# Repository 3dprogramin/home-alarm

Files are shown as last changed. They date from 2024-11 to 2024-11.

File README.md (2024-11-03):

# Home Alarm

**Home Alarm** is an Arduino-based project designed for home security. This project utilizes an ESP32 microcontroller, a PIR sensor for motion detection, an RGB LED, and a keypad for user interactions. The system communicates with an Express.js server to ensure robust notifications and intruder alerts.

<p align="center">
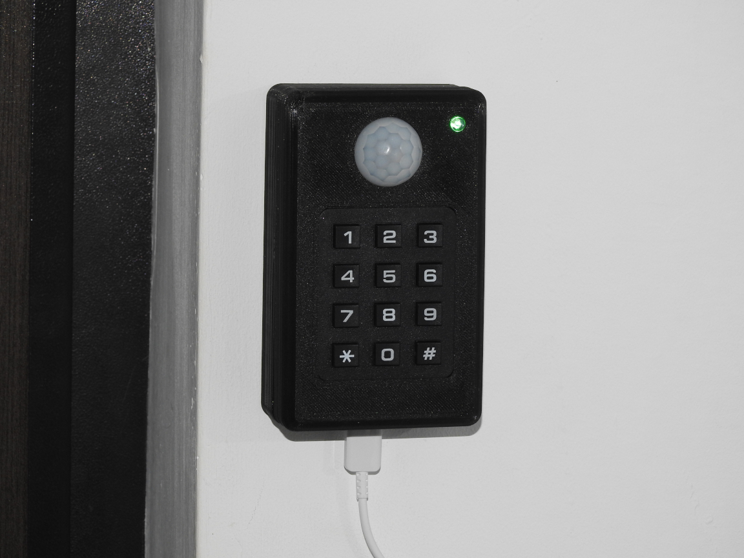
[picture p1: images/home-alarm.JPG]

</p>

## Project Structure
```perl
home-alarm/
├── src/               # Arduino code (PlatformIO)
├── server/            # Express.js server code
├── schematics/        # Wiring schematics (KiCad and PDF)
└── design/            # 3D design files (FreeCAD and .obj)
```

## Overview

The **Home Alarm** system operates as follows:
1. **Startup & Connection**: The ESP32 connects to a predefined WiFi network upon startup.
2. **Arming**: Press the * key on the keypad to activate the alarm. The system provides a 15-second grace period to exit the room without triggering the alarm.
3. **Detection & Notification**: 
   - If the PIR sensor detects motion while armed, the system initiates a 30-second window for PIN entry.
   - If the correct PIN is entered, the system disarms itself and sends a notification to the server to stop any further alerts.
   - Failure to enter the correct PIN within 30 seconds triggers the Express.js server to send an alert via Discord.
4. **Self-Arming**: If the system remains inactive for 12 hours and no motion is detected, it arms itself automatically.
5. **LED Indicators**:
   - **Green**: Powered on but not armed.
   - **Red**: Armed and ready.
   - **Blue**: Motion detected and awaiting PIN entry.
  
## Requirements

### Hardware
- **ESP32 Microcontroller**
- **PIR sensor**
- **RGB LED** (and 3 x 220 ohm resistors)
- **3x4 Matrix Keypad**
- **3D printer** for printing the case
  
### Software
- **PlatformIO** for Arduino code development
- **Node.js** for running the Express.js server
- **KiCad** for viewing/modifying schematics (*optional*)
- **FreeCAD** for viewing/modifying 3D design files (*optional*)

## Configuration

Before uploading the Arduino code, modify the following variables in `src/main.cpp`:

```cpp
const char *ssid = "YOUR_WIFI_SSID";
const char *password = "YOUR_WIFI_PASSWORD";
const char *serverURL = "YOUR_API_SERVER_URL";
const char *serverToken = "YOUR_API_SERVER_TOKEN";  // something unique, make sure the same token is used in server
const char *alarmPin = "YOUR_ALARM_PIN";            // e.g 1234#
```

There are other configurations that can be modified to your own needs, most of them being defined with `#define`

## Server Configuration

1. Navigate to the `server/` directory
2. Copy the `.env.sample` file and rename it to `.env`
3. Modify the variables in the `.env` file as needed:

```bash
PORT=3000
TOKEN=your_server_token
TRIGGER_DELAY=30000
DISCORD_WEBHOOK_ACTIVATED=https://discord.com/api/webhooks/your_activated_webhook
DISCORD_WEBHOOK_TRIGGER=https://discord.com/api/webhooks/your_trigger_webhook
```

The `TOKEN` inside your arduino code and the token inside the server need to match. It is used to authenticate the API calls made from the device to the server.

## Installation

### Arduino Code

1. Ensure **PlatformIO** is installed in your IDE (e.g., VSCode).
2. Navigate to `src/` folder
3. Upload the code to your ESP32

### Server Code

1. Navigate to the `server/` folder
2. Run the following commands:

```bash
npm install
npm start
```

## Operation

1. Power on the device.
2. Once connected to WiFi, arm the system by pressing the `*` key.
3. Leave the room within 15 seconds.
4. If an intruder is detected, enter the correct PIN on the keypad within 30 seconds to disarm.
5. If not disarmed, the Express.js server sends a Discord notification.

## Schematics and Design

- **Schematics**: The wiring schematics are created in **KiCad** and rendered to PDF for easy viewing. The original KiCad project files are included for any custom modifications.
- **3D Design**: The design is created in **FreeCAD** and exported to .obj files for use in 3D printing or rendering. The original FreeCAD project files are also included for custom modifications.

## License

This project is open-source and available under the MIT License.

## Contributing

Feel free to fork the repository, submit pull requests, or open issues for improvements or bug fixes.

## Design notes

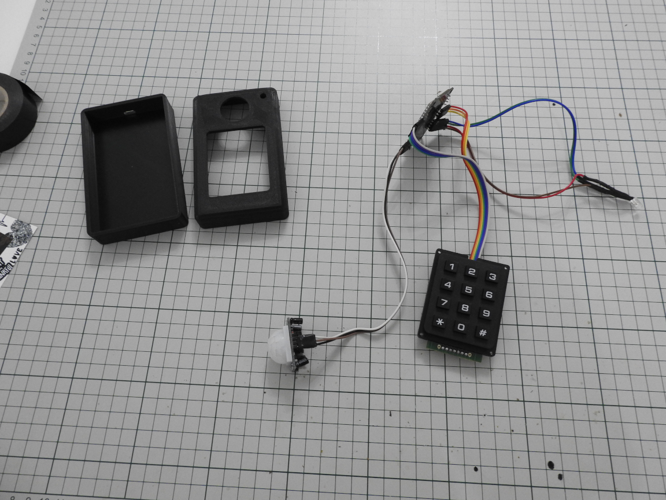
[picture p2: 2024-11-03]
images/before-mount.JPG

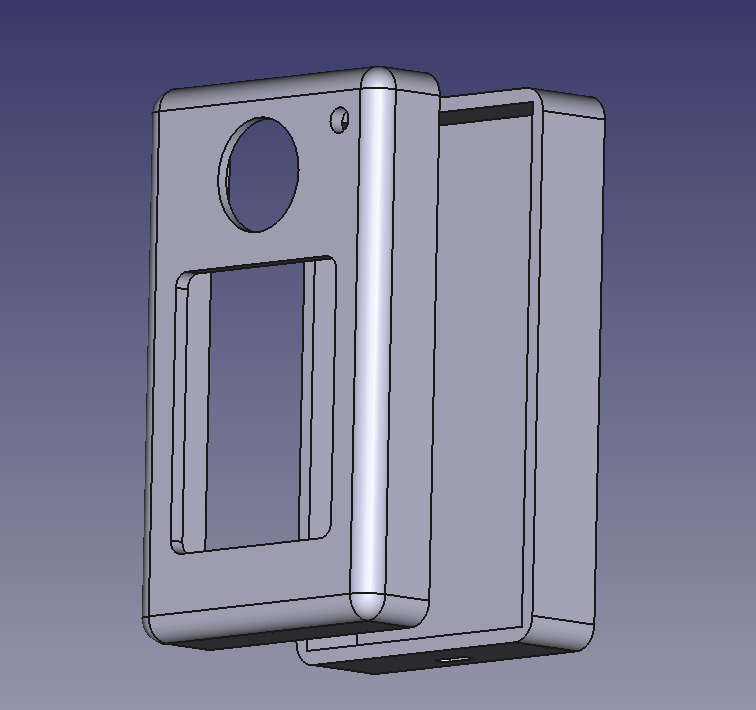
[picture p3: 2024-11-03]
images/case.png

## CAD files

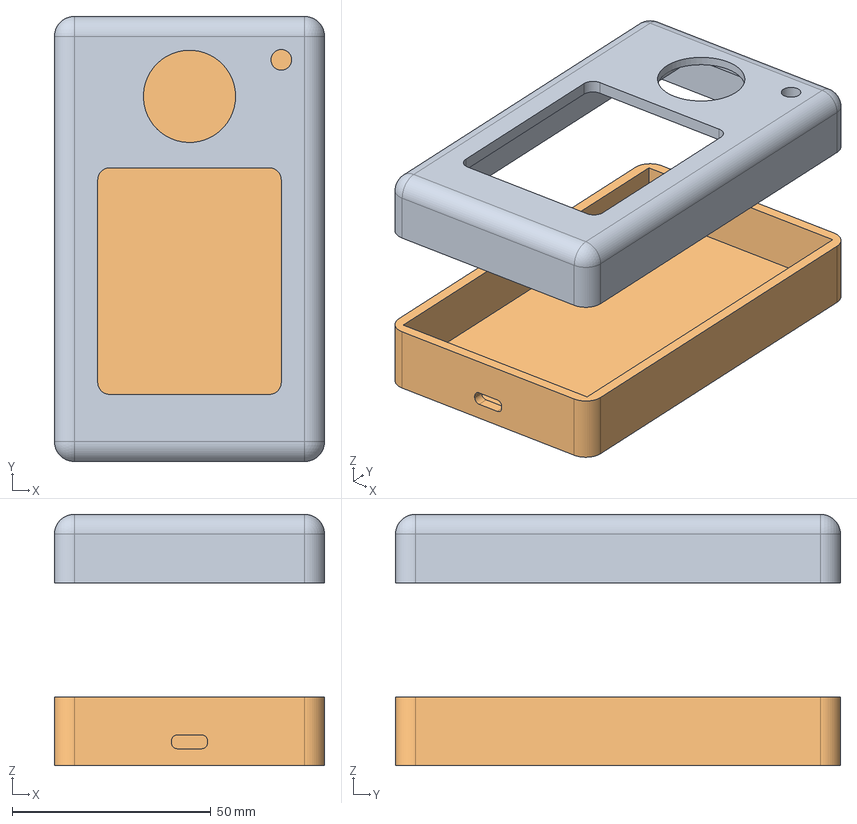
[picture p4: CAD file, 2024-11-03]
design/home-alarm.FCStd
68.0 x 112.0 x 63.2 mm
front
back

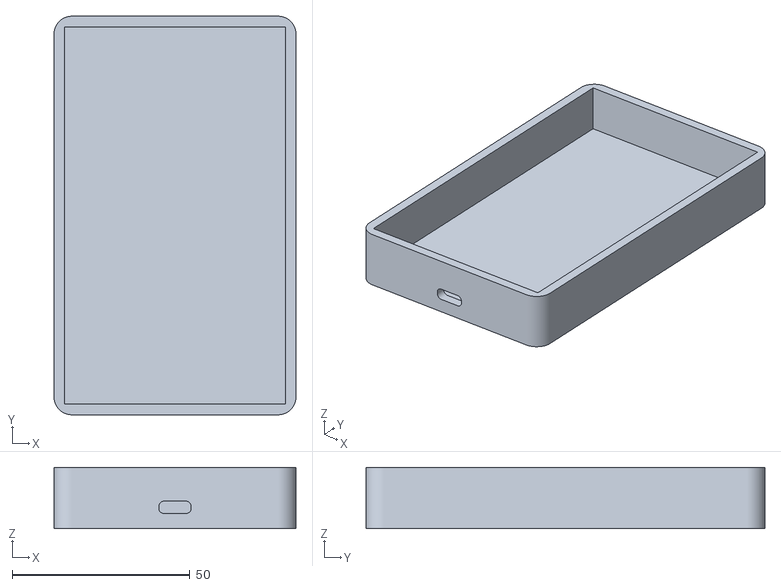
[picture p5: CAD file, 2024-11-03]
design/back.obj
68.0 x 112.0 x 17.2

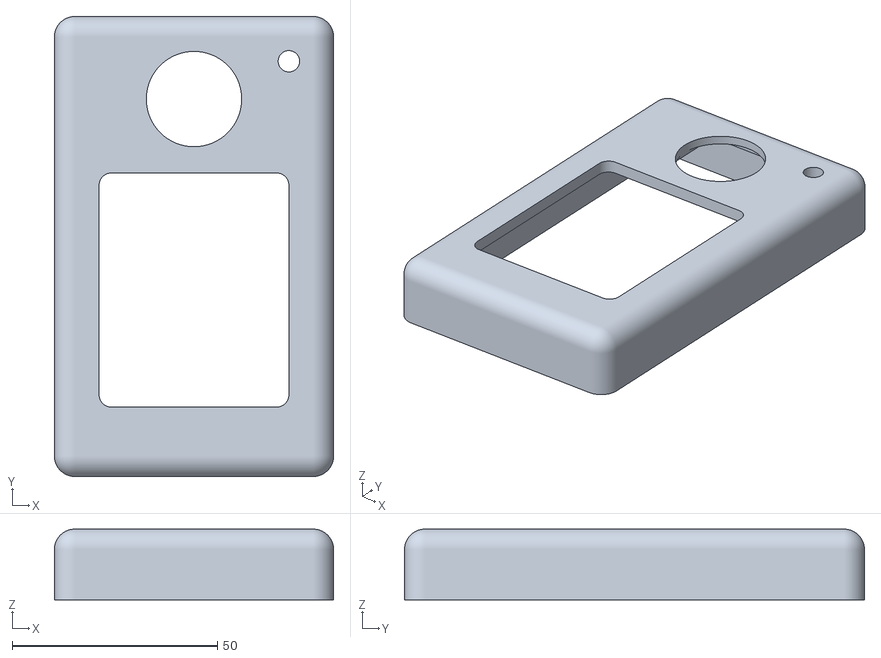
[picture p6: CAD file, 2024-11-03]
design/front.obj
68.0 x 112.0 x 17.2

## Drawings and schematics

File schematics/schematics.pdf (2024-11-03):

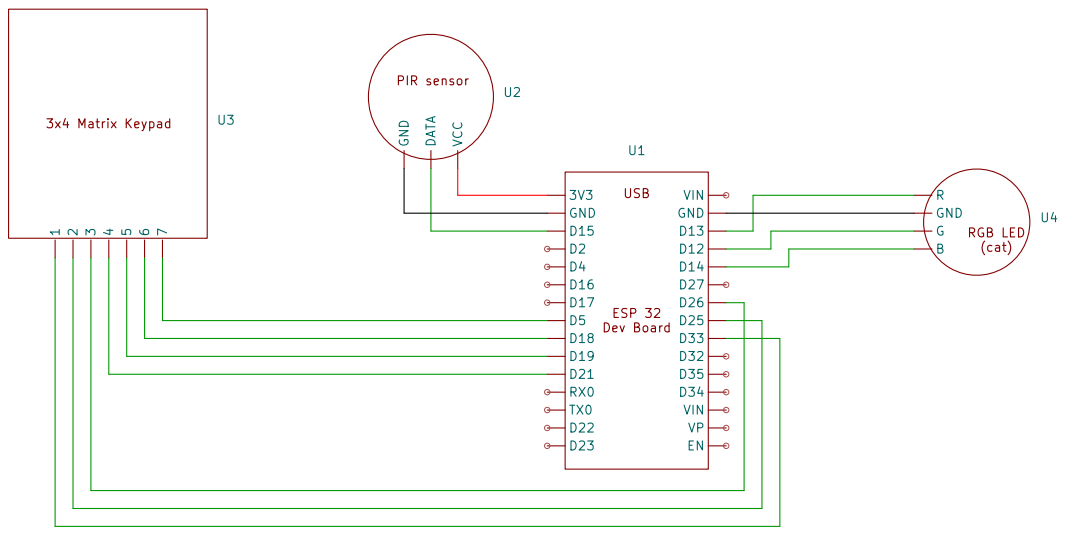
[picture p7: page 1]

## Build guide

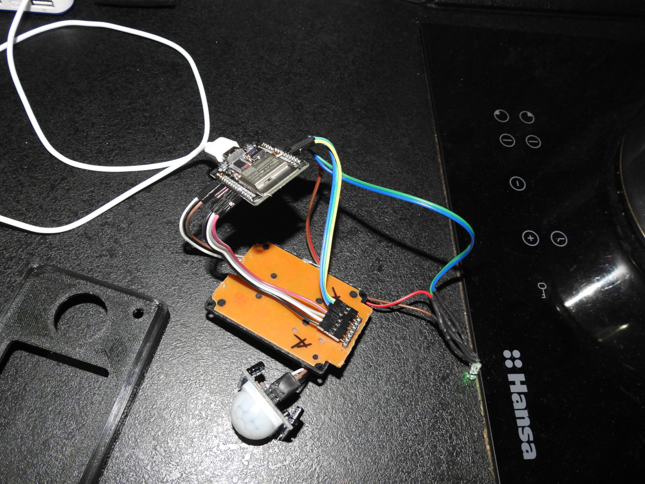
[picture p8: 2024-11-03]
images/wiring.JPG

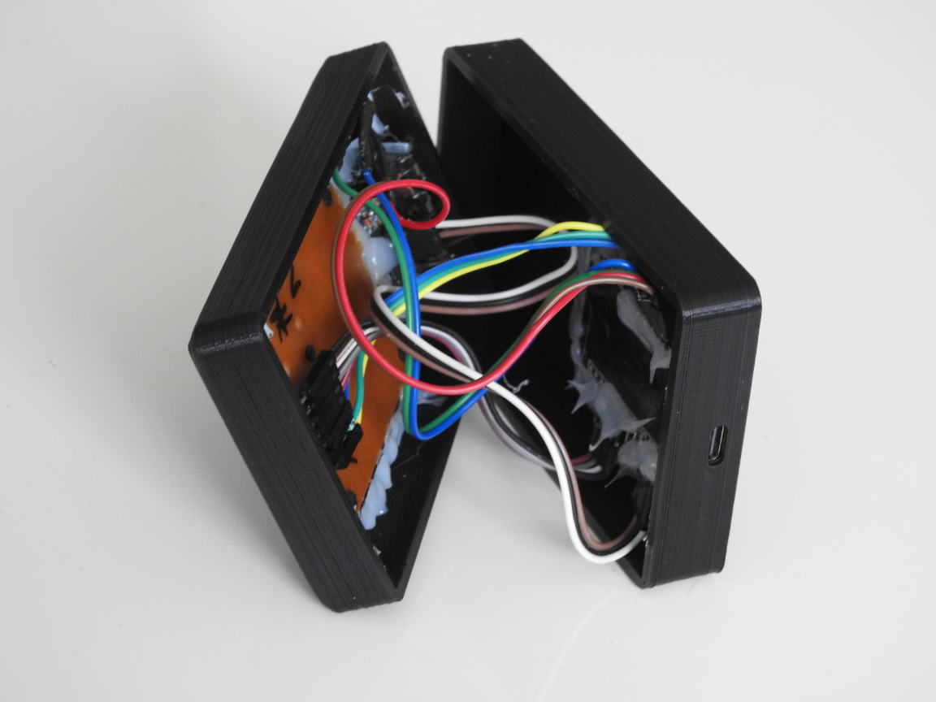
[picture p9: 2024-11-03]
images/case-printed.JPG

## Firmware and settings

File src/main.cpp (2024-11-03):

#include <Arduino.h>
#include <Keypad.h>
#include <WiFi.h>
#include <HTTPClient.h>

// -------------------------------------------
// CONFIGURATION
// -------------------------------------------
// GPIO pins where the PIR sensor, RGB LED and 4x3 matrix keypad are connected
// -------------------------------------------
#define PIR_SENSOR_PIN 15
#define RGB_LED_RED 13
#define RGB_LED_GREEN 12
#define RGB_LED_BLUE 14

// -------------------------------------------
// 3x4 matrix keypad
// -------------------------------------------
const byte ROWS = 4; // four rows
const byte COLS = 3; // three columns
// ------
// Pins
// ------
// 1  2  3  4  5  6  7
// 33 25 26 21 19 18 5
byte rowPins[ROWS] = {25, 5, 18, 21};
byte colPins[COLS] = {26, 33, 19};

// -------------------------------------------
// WiFi
// -------------------------------------------
const char *ssid = "YOUR_WIFI_SSID";
const char *password = "YOUR_WIFI_PASSWORD";
const char *hostname = "home-alarm";

// -------------------------------------------
// HTTPS server
// -------------------------------------------
const char *serverURL = "YOUR_API_SERVER_URL";
const char *serverToken = "YOUR_API_SERVER_TOKEN";

// -------------------------------------------
// Alarm PIN
// -------------------------------------------
// how much time the user has to type the PIN after the alarm is triggered
// we add 2 more seconds here compared to the server side
// just to make sure the new trigger is not resetting the old one
// default: 32000 (32 seconds)
#define ALARM_TRIGGER_TIME_WINDOW 32000
// when arming the system, wait for a bit so the user can leave the room
// default: 15000 (15 seconds)
#define ARMED_DELAY 15000
// if the user does not arm the system in this time, the system will arm itself
// default: 720 (12 hours)
#define AUTO_ARM_MINUTES 720
const char *alarmPin = "YOUR_ALARM_PIN"; // eg 1234#

// -------------------------------------------
// END CONFIGURATION
// -------------------------------------------

char keys[ROWS][COLS] = {
    {'1', '2', '3'},
    {'4', '5', '6'},
    {'7', '8', '9'},
    {'*', '0', '#'}};

Keypad keypad = Keypad(makeKeymap(keys), rowPins, colPins, ROWS, COLS);

// Variable to store the PIR sensor status
bool armed = false;
bool triggered = false;
unsigned long triggerTime = 0;
unsigned long autoArmTime = 0;
unsigned long lastAutoArmUpdateTime = 0;
// if the system detects motion while it's still not armed
// update the autoArmTime to the current time but only once every minute
const int updateAutoArmTime = 60000;
String pinBuffer = "";
bool standby = false;
// for controlling the green LED brightness
const int greenPWMChannel = 1;
const int freq = 5000;
const int resolution = 8;

// Set the color of the RGB LED
// If only green is true, set the LED to low brightness
// We do this because the green LED is very bright at night
void setLEDColor(bool red, bool green, bool blue, bool lowGreenBrightness = false)
{
  digitalWrite(RGB_LED_RED, red);
  // for green, we control the brightness
  if (green)
  {
    if (lowGreenBrightness)
    {
      ledcWrite(greenPWMChannel, 5);
    }
    else
    {
      ledcWrite(greenPWMChannel, 255);
    }
  }
  else
  {
    ledcWrite(greenPWMChannel, 0);
  }

  digitalWrite(RGB_LED_BLUE, blue);
}

// Check if connected to WiFi, if not, try to connect
void checkInitWiFi()
{
  // make sure WiFi is connected
  // we will run the init inside the loop, in case the connection is lost
  if (WiFi.status() == WL_CONNECTED)
  {
    return;
  }
  WiFi.mode(WIFI_STA);
  WiFi.config(INADDR_NONE, INADDR_NONE, INADDR_NONE, INADDR_NONE);
  WiFi.setHostname(hostname);

  WiFi.begin(ssid, password);
  Serial.print("Connecting to WiFi...");
  while (WiFi.status() != WL_CONNECTED)
  {
    setLEDColor(true, false, true);
    Serial.print('.');
    delay(100);
    setLEDColor(false, false, false);
    delay(100);
  }

  Serial.println("WiFi connected");
  Serial.print("IP Address: ");
  Serial.println(WiFi.localIP());
  Serial.print("HostName: ");
  Serial.println(WiFi.getHostname());
  Serial.print("RRSI: ");
  Serial.println(WiFi.RSSI());
  setLEDColor(false, true, false, true);
}

// Send HTTP(s) GET request
void sendGETRequest(String url)
{
  HTTPClient http;
  int responseCode;
  String responseBody;

  // based on URL protocol use HTTP or HTTPS
  if (url.startsWith("https://"))
  {
    WiFiClientSecure client;
    client.setInsecure();

    http.begin(client, url); // HTTPS connection
    responseCode = http.GET();
  }
  else if (url.startsWith("http://"))
  {
    WiFiClient client;
    http.begin(client, url); // HTTP connection
    responseCode = http.GET();
  }
  // end connection and return response
  http.end();
  Serial.print("HTTP response code: ");
  Serial.println(responseCode);
}

// Activate the alarm, but slowly, so the user can leave the room
void activate()
{
  int counter = 0;
  int dynamicDelay = 500;
  // blink the LED in blue
  Serial.println("Activating alarm in " + String(ARMED_DELAY / 1000) + " seconds");
  while (counter < ARMED_DELAY)
  {
    setLEDColor(true, false, false);
    delay(dynamicDelay);
    setLEDColor(false, false, false);
    delay(dynamicDelay);
    counter += dynamicDelay * 2;
    // decrease the delay each time, but not more than 100ms
    if (dynamicDelay > 50)
    {
      dynamicDelay -= 25;
    }
  }
  armed = true;
  Serial.println("Armed");
  setLEDColor(true, false, false);
  pinBuffer = "";
  // send request to server that tells the alarm was activated
  String url = String(serverURL) + "/activate?token=" + String(serverToken);
  sendGETRequest(url);
}

// PIN was typed correctly, reset everything and send a request to the server
void pinTypedCorrectly()
{
  // blink green 3 times
  setLEDColor(false, true, false);
  delay(100);
  setLEDColor(false, false, false);
  delay(100);
  setLEDColor(false, true, false);
  delay(100);
  setLEDColor(false, false, false);
  delay(100);
  setLEDColor(false, true, false);
  delay(100);
  setLEDColor(false, false, false);
  delay(100);
  setLEDColor(false, true, false, true);
  Serial.println("PIN verified, alarm stopped");
  triggered = false;
  armed = false;
  triggerTime = 0;
  pinBuffer = "";
  standby = false;
  autoArmTime = millis();
  // send request to server that tells the alarm was stopped by the owner
  // this will make the server stop the notification process
  String url = String(serverURL) + "/stop?token=" + String(serverToken);
  sendGETRequest(url);
}

void setup()
{
  // Start the serial communication to monitor the sensor status
  Serial.begin(115200);

  // PIR sensor pin as input
  pinMode(PIR_SENSOR_PIN, INPUT);

  // RGB LED pins as output
  pinMode(RGB_LED_RED, OUTPUT);

  // we handle the green LED with PWM, so we can control the brightness
  ledcSetup(greenPWMChannel, freq, resolution);
  ledcAttachPin(RGB_LED_GREEN, greenPWMChannel);

  pinMode(RGB_LED_BLUE, OUTPUT); // We won't use blue in this case

  // set the led to all 3 colors to know it's working
  setLEDColor(true, false, false);
  delay(250);
  setLEDColor(false, true, false);
  delay(250);
  setLEDColor(false, false, true);
  delay(250);
  setLEDColor(false, false, false);
  delay(250);
}

void loop()
{
  // check if the WiFi is connected
  checkInitWiFi();

  // initially, we're not armed and not triggered
  // if the user presses the * key, we'll arm the system
  char key = keypad.getKey();

  // used for debugging
  if (key)
  {
    Serial.print("Key pressed: ");
    Serial.println(key);
  }

  // autoArmTime and lastAutoArmUpdateTime are dependent on millis()
  // but millis resets after ~40 days, so we need to handle the overflow
  if (millis() < autoArmTime || millis() < lastAutoArmUpdateTime)
  {
    // Handle the overflow by resetting autoArmTime
    // This assumes that an overflow has occurred, so we reset autoArmTime to millis()
    Serial.println("millis() overflow detected, resetting autoArmTime");
    autoArmTime = millis();
    lastAutoArmUpdateTime = millis();
  }

  // check if alarm is triggered
  if (triggered)
  {
    // if the alarm is triggered, and the time window has passed, reset the alarm
    if (millis() - triggerTime > ALARM_TRIGGER_TIME_WINDOW)
    {
      triggered = false;
      triggerTime = 0;
      pinBuffer = "";
      standby = false;
      setLEDColor(true, false, false);
      Serial.println("Alarm reset");
      return;
    }

    // if no key was typed, return
    if (!key)
    {
      return;
    }

    // if a key was typed, add it to the buffer and compare it with the alarm pin
    pinBuffer += key;

    // if the buffer has more than 100 characters, keep only the last 50
    // probably a bit overkill, but just to make sure it's in the user range
    // and also to avoid memory issues
    if (pinBuffer.length() > 100)
    {
      pinBuffer = pinBuffer.substring(50);
    }

    // check if the buffer contains the alarm pin
    if (pinBuffer.endsWith(alarmPin))
    {
      pinTypedCorrectly();
    }
    else
    {
      setLEDColor(false, false, false);
      delay(50);
      setLEDColor(false, false, true);
    }
    return;
  }

  // -------------------------------------------
  // Read the PIR sensor value
  // -------------------------------------------
  bool motionDetected = digitalRead(PIR_SENSOR_PIN);

  // if we are not armed, check for key presses
  if (!armed)
  {
    // the user can only arm the system by pressing the * key
    if (key == '*')
    {
      activate();
    }
    // if a different key is pressed, blink the LED
    else if (key)
    {
      setLEDColor(false, false, false);
      delay(50);
      setLEDColor(false, true, false);
    }

    // if the user does not arm the system after a certain time, the system will arm itself
    if (millis() - autoArmTime > AUTO_ARM_MINUTES * 60000)
    {
      Serial.println("Automatically activating the alarm after " + String(AUTO_ARM_MINUTES) + " minutes");
      activate();
    }

    // if there is motion detected, reset the autoArmTime
    // this way the system will not arm itself if the user is in the room
    if (motionDetected && millis() - lastAutoArmUpdateTime > updateAutoArmTime)
    {
      Serial.println("Motion detected while not armed, resetting auto arm time");
      autoArmTime = millis();
      lastAutoArmUpdateTime = millis();
    }
    return;
  }

  // Check if motion is detected
  if (motionDetected)
  {
    triggered = true;
    triggerTime = millis();
    // send request to server
    // we don't care about the response, we just want to trigger the alarm on the server side
    // the server will send a notification to the user instead of the alarm sending it
    // this way we know for sure if somebody is cutting the power to the alarm
    // the notification will be sent to the user regardless of the alarm having power or not
    String url = String(serverURL) + "/trigger?token=" + String(serverToken);
    sendGETRequest(url);
    setLEDColor(false, false, true);
    Serial.println("Alarm triggered");
  }
  else if (!standby)
  {
    // we do it with standby to avoid resetting the LED color to green on each loop
    Serial.println("No motion detected - standby");
    setLEDColor(true, false, false);
    standby = true;
  }
}
